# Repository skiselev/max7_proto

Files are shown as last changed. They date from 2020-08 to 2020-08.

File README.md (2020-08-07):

# MAX7 Proto
Prototyping Board for Altera MAX7000 CPLDs

## Table of Content
* [Introduction](#introduction)
* [Hardware Documentation](#hardware-documentation)
  * [Schematic and PCB Layout](#schematic-and-pcb-layout)
  * [Connectors and Jumpers](#connectors-and-jumpers)
  * [Bill of Materials](#bill-of-materials)
* [Programming](#programming)

## Introduction

MAX7 Proto is a prototyping board based on Altera MAX7000 series CPLDs. The board has pin headers on both sides, and it can be easily mounted on a breadboard. It also includes a 3.3V LDO, so that MAX7000AE CPLDs can be used. A DIP-8 oscillator socket is provided for the designs that requre a clock.

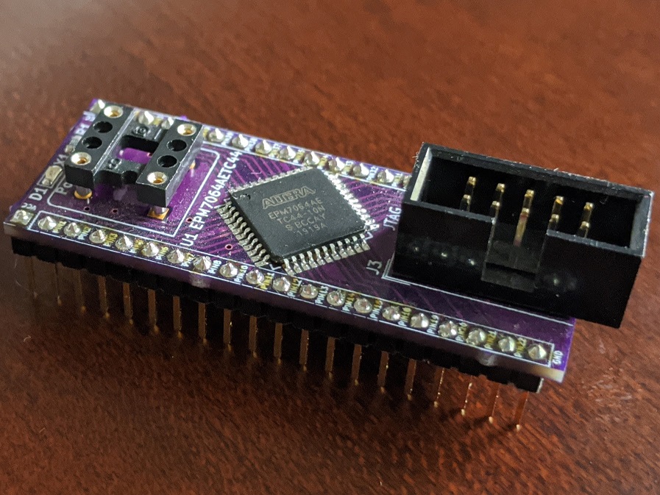
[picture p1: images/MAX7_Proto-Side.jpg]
MAX7 Proto Assembled Board Side View


## Hardware Documentation

### Schematic and PCB Layout

[Schematic](KiCad/MAX7_Proto-Schematic.pdf)

[PCB Layout](KiCad/MAX7_Proto-Board.pdf)

### Connectors and Jumpers

#### J1, J2 - CPLD Breakout Pin Headers
Pin   | Signal Name | Description               | Pin   | Signal Name | Description
----- | ----------- | ------------------------- | ----- | ----------- | -------------------------
J1-1  | VCC         | Power Supply - +5V        | J2-1  | VCC         | Power Supply - +5V
J1-2  | PIN1_TDI    | CPLD Pin 1; JTAG TDI; I/O | J2-2  | PIN44       | CPLD Pin 44; I/O
J1-3  | PIN2        | CPLD Pin 2; I/O           | J2-3  | PIN43       | CPLD Pin 43; I/O
J1-4  | PIN3        | CPLD Pin 3; I/O           | J2-4  | PIN42       | CPLD Pin 42; I/O
J1-5  | PIN5        | CPLD Pin 5; I/O           | J2-5  | PIN40       | CPLD Pin 40; In, OE2, GCLK2
J1-6  | PIN6        | CPLD Pin 6; I/O           | J2-6  | PIN39       | CPLD Pin 39; In, GCLRn
J1-7  | PIN7_TMS    | CPLD Pin 7; JTAG TMS; I/O | J2-7  | PIN38       | CPLD Pin 38; In, OE1n
J1-8  | PIN8        | CPLD Pin 8; I/O           | J2-8  | PIN37       | CPLD Pin 37; In, GCLK2
J1-9  | PIN10       | CPLD Pin 10; I/O          | J2-9  | PIN35       | CPLD Pin 35; I/O
J1-10 | PIN11       | CPLD Pin 11; I/O          | J2-10 | PIN34       | CPLD Pin 34; I/O
J1-11 | PIN12       | CPLD Pin 12; I/O          | J2-11 | PIN33       | CPLD Pin 33; I/O
J1-12 | PIN13       | CPLD Pin 13; I/O          | J2-12 | PIN32_TDO   | CPLD Pin 32; JTAG TDO; I/O
J1-13 | PIN14       | CPLD Pin 14; I/O          | J2-13 | PIN31       | CPLD Pin 31; I/O
J1-14 | PIN15       | CPLD Pin 15; I/O          | J2-14 | PIN30       | CPLD Pin 30; I/O
J1-15 | PIN18       | CPLD Pin 18; I/O          | J2-15 | PIN28       | CPLD Pin 28; I/O
J1-16 | PIN19       | CPLD Pin 19; I/O          | J2-16 | PIN27       | CPLD Pin 27; I/O
J1-17 | PIN20       | CPLD Pin 20; I/O          | J2-17 | PIN26_TCK   | CPLD Pin 26; JTAG TCK; I/O
J1-18 | PIN21       | CPLD Pin 21; I/O          | J2-18 | PIN25       | CPLD Pin 25; I/O
J1-19 | PIN22       | CPLD Pin 22; I/O          | J2-19 | PIN23       | CPLD Pin 23; I/O
J1-20 | GND         | Ground                    | J2-20 | GND         | Ground

#### J3 - JTAG - CPLD
Pin  | Signal Name | Description      | Pin  | Signal Name | Description
---- | ----------- | ---------------- | ---- | ---------- | ----------------
1    | TCK         | Test Clock       | 2    | GND         | Ground
3    | TDO         | Test Data Output | 4    | 3.3V        | Power Supply - +3.3V
5    | TMS         | Test Mode Select | 6    | PIN2        | No Connect
7    | NC          | No Connect       | 8    | NC          | No Connect
9    | TDI         | Test Data Input  | 10   | GND         | Ground

#### JP1 - LDO Bypass
Solder instead of U2 LDO when using a 5V CPLD

#### JP2 - Oscillator Connect
Solder to connect X1 oscillator to CPLD pin 37 / GCLK1

### Bill of Materials

[MAX7_Proto project on Mouser.com](https://www.mouser.com/ProjectManager/ProjectDetail.aspx?AccessID=f840bea3ac) - View and order all components except of the PCB.

[MAX7_Proto project on OSH Park](https://oshpark.com/shared_projects/AL0pME1G) - View and order the PCB.

Component type     | Reference | Description                                 | Quantity | Possible sources and notes 
------------------ | --------- | ------------------------------------------- | -------- | --------------------------
PCB                |           | MAX7 Proto PCB                              | 1        | Order from a PCB manufacturer of your choice using provided Gerber or KiCad files
Capacitor          | C1        | 10nF	0603 SMT                               | 1        | Mouser [77-V0603Y103KXJAC31X](https://www.mouser.com/ProductDetail/77-V0603Y103KXJAC31X)
Capacitor          | C2 - C7   | 100nF 0603 SMT                              | 6        | Mouser [77-VJ0603Y104JXJPBC](https://www.mouser.com/ProductDetail/77-VJ0603Y104JXJPBC)
Capacitor          | C8, C9    | 10uF	1210 SMT                               | 2        | Mouser [74-593D106X9016A2TE3](https://www.mouser.com/ProductDetail/74-593D106X9016A2TE3)
LED                | D1        | 0603 SMT Power/Green                        | 1        | Mouser [78-VLMG1300-GS08](https://www.mouser.com/ProductDetail/78-VLMG1300-GS08)
Connector          | J1, J2    | Pin Header 1x20, 2.54 mm pitch              | 2        | Mouser [649-68000-220HLF](https://www.mouser.com/ProductDetail/649-68000-220HLF)
Connector          | J5        | Pin Header 2x5, 2.54 mm pitch, Shrouded     | 1        | Mouser [710-61201021621](https://www.mouser.com/ProductDetail/710-61201021621)
Resistor           | R1        | 1 kOhm 0603 SMT                             | 1        | Mouser [71-CRCW0603-1.0K-E3](https://www.mouser.com/ProductDetail/71-CRCW0603-1.0K-E3)
Resistor           | R2 - R5   | 10 kOhm 0603 SMT                            | 4        | Mouser [71-CRCW0603-10K-E3](https://www.mouser.com/ProductDetail/71-CRCW0603-10K-E3) 
Integrated Circuit | U1        | EPM7064AETC44, Altera MAX 7000AE CPLD, TQFP-44 | 1     | Mouser [989-EPM7064AETC4410N](https://www.mouser.com/ProductDetail/989-EPM7064AETC4410N)
Integrated Circuit | U2        | TPS79333-EP                                 | 1        | Mouser [595-TPS79333DBVR](https://www.mouser.com/ProductDetail/595-TPS79333DBVR)
Socket             | X1        | Half can / DIP-8 Oscillator Socket          | 1        | Mouser [535-1108800](https://www.mouser.com/ProductDetail/535-1108800)
Crystal Oscillator | X1        | Half can / DIP-8 Oscillator, 5V             | 1        | Optional, frequency depends on the design requirements

## Programming

Use free Altera Quartus II 13.0sp1 Web Edition to program the CPLD. Newer Quartus versions do not support Altera MAX7000 CPLDs.

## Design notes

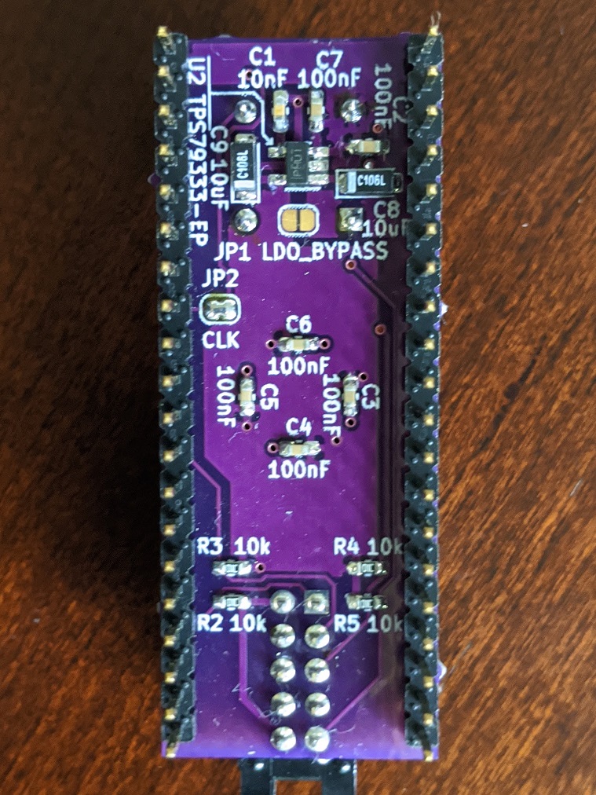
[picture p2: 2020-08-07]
images/MAX7_Proto-Bottom.jpg

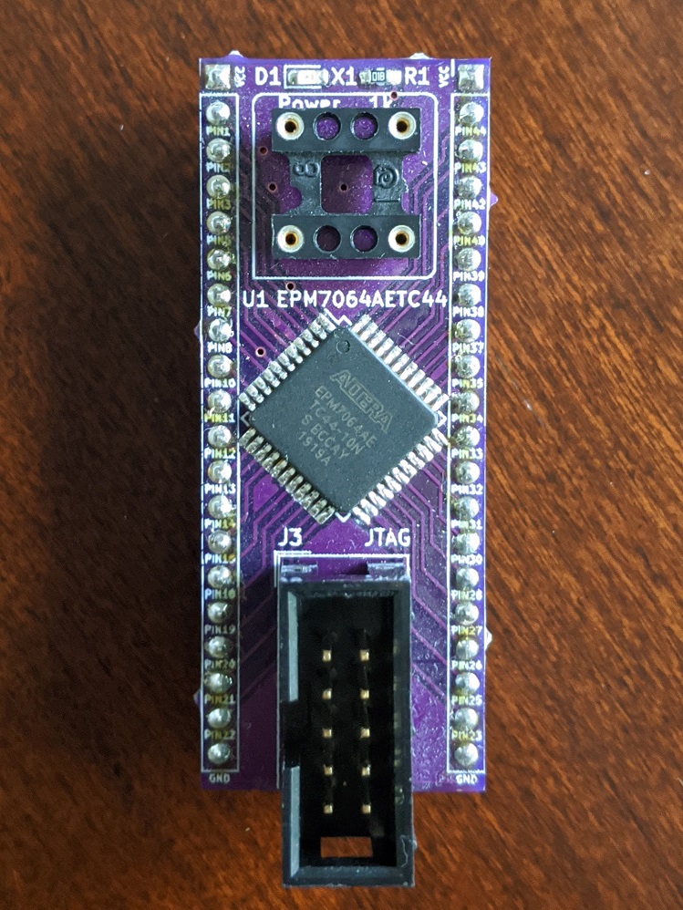
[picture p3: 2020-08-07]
images/MAX7_Proto-Top.jpg

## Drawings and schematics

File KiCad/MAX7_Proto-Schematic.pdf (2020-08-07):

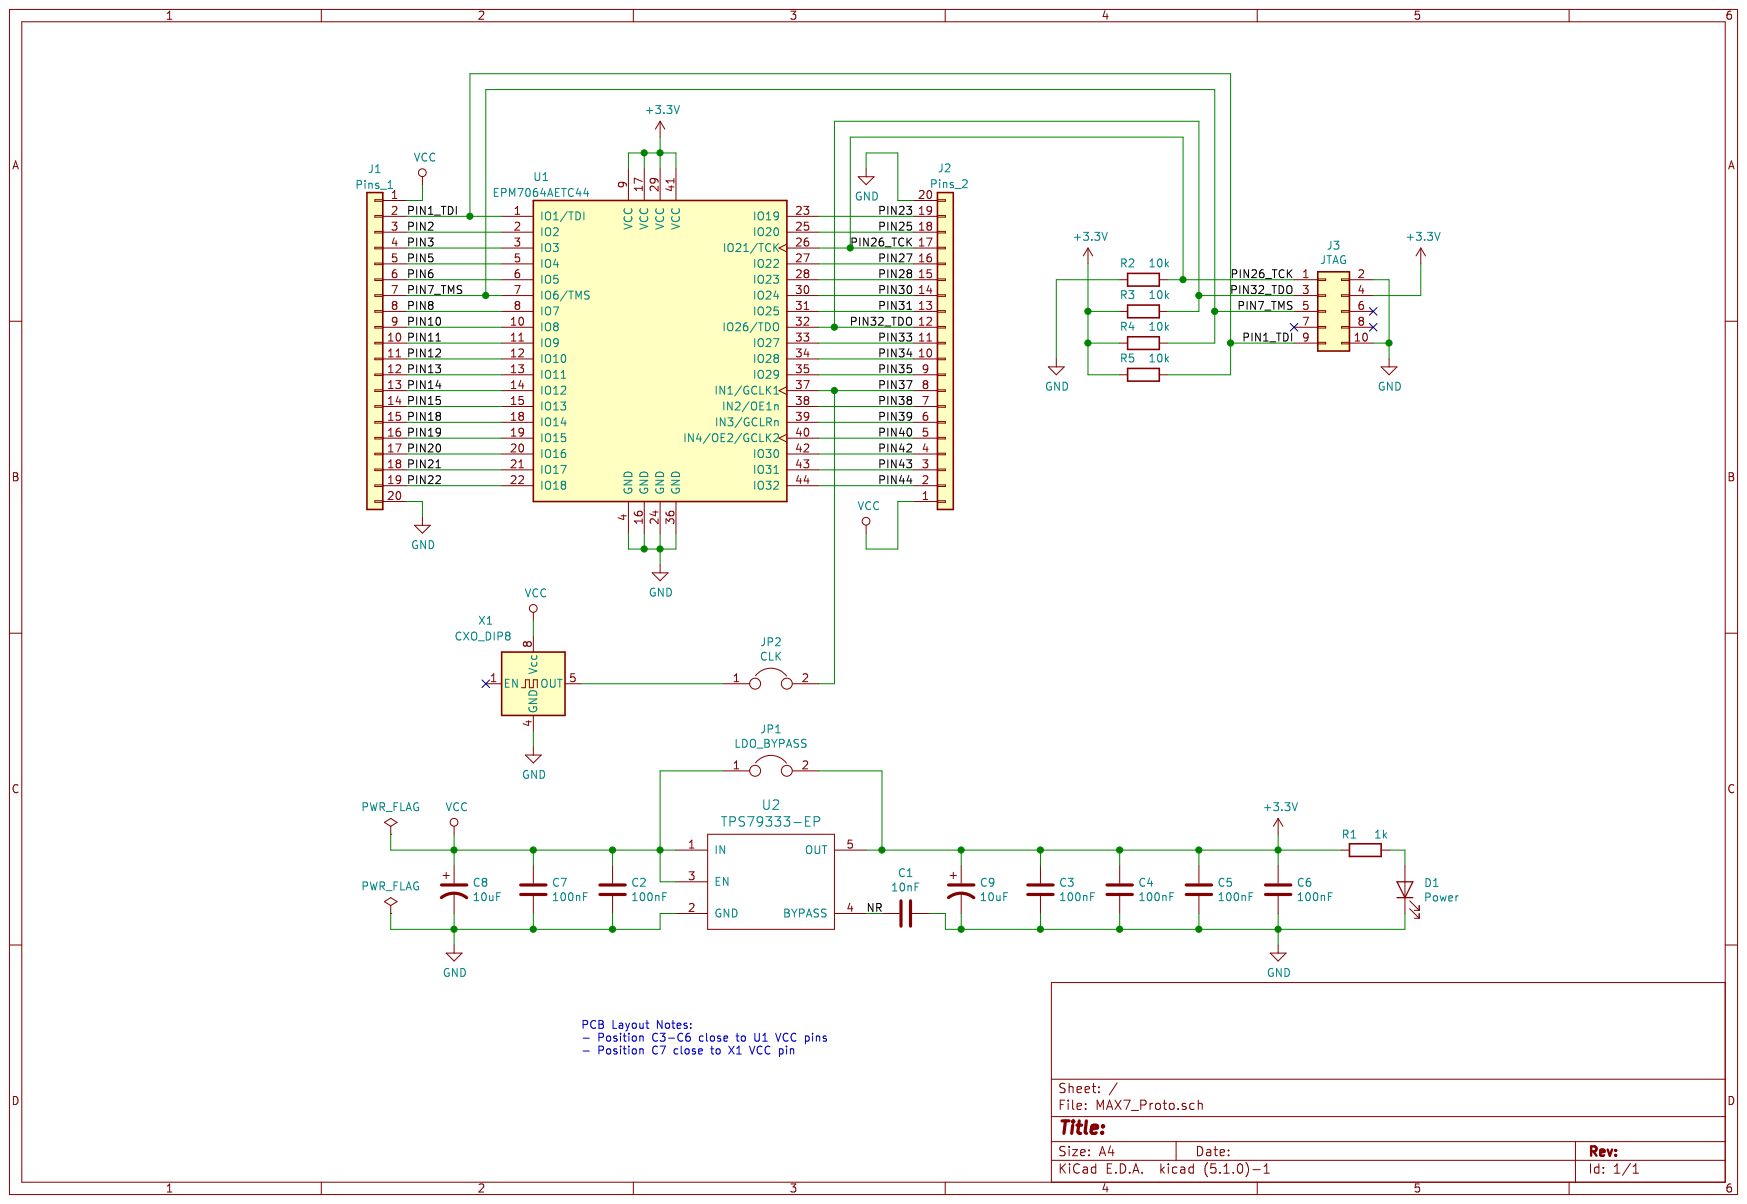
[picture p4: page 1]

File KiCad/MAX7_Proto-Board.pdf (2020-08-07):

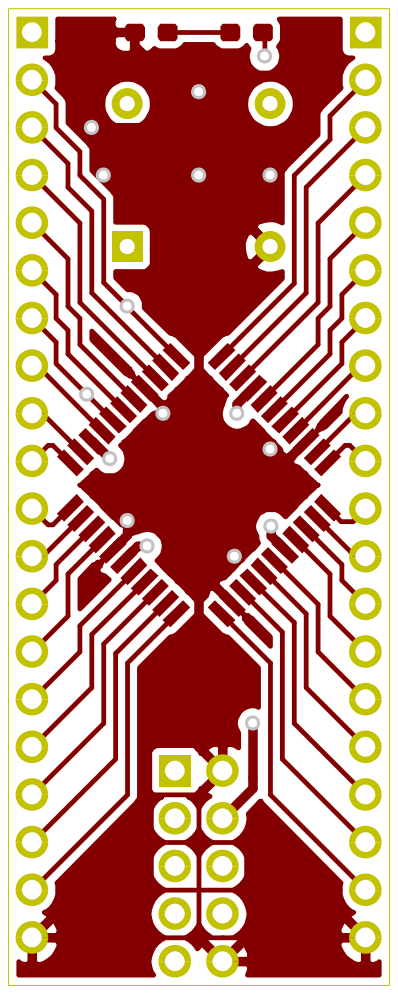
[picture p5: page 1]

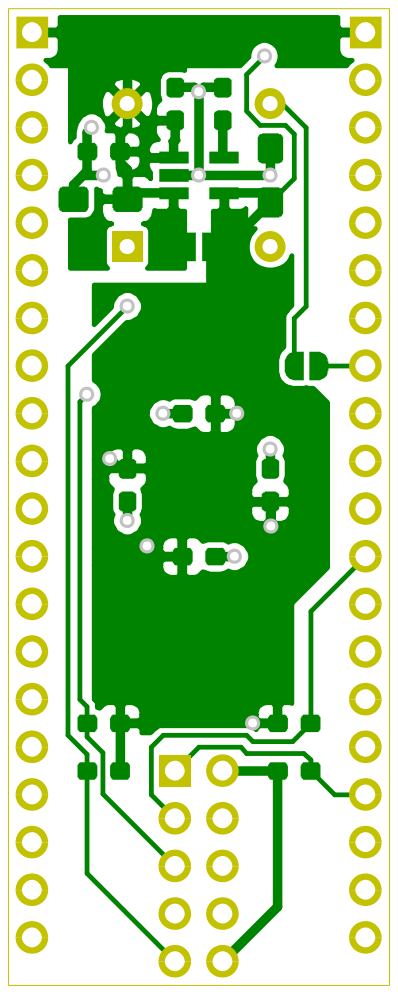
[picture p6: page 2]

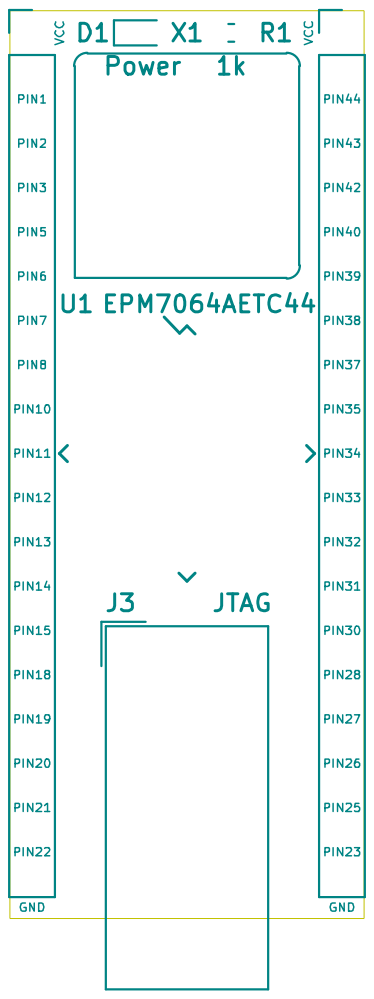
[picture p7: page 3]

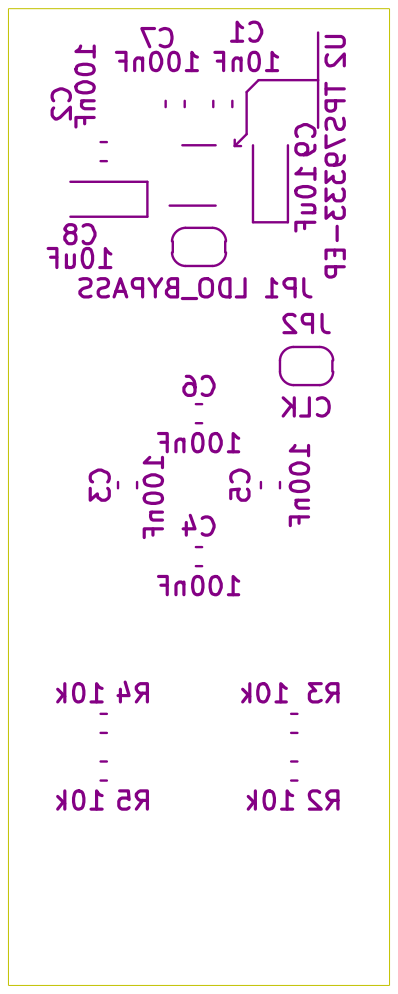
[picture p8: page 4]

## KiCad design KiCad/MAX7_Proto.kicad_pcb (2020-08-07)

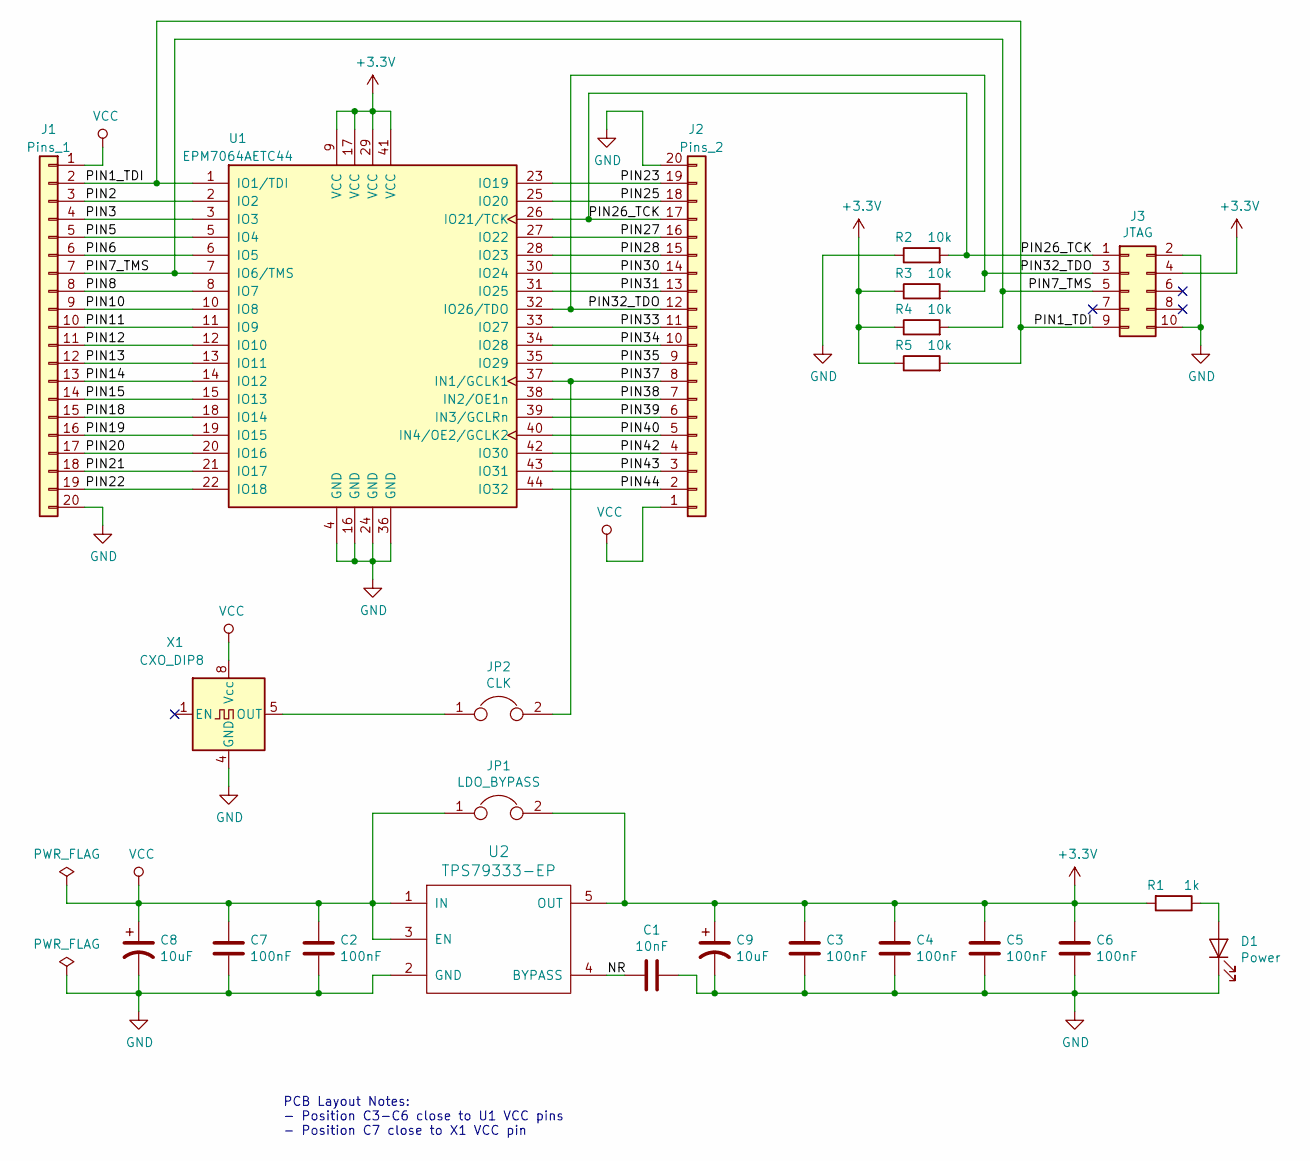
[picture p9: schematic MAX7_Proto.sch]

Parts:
C1: 10nF; C_0603_1608Metric_Pad1.05x0.95mm_HandSolder
C2, C3, C4, C5, C6, C7: 100nF; C_0603_1608Metric_Pad1.05x0.95mm_HandSolder
C8, C9: 10uF; CP_EIA-3216-10_Kemet-I_Pad1.58x1.35mm_HandSolder
D1: Power; LED_0603_1608Metric_Pad1.05x0.95mm_HandSolder
J1: Pins_1; PinHeader_1x20_P2.54mm_Vertical
J2: Pins_2; PinHeader_1x20_P2.54mm_Vertical
J3: JTAG; IDC-Header_2x05_P2.54mm_Vertical
JP1: LDO_BYPASS; SolderJumper-2_P1.3mm_Open_RoundedPad1.0x1.5mm
JP2: CLK; SolderJumper-2_P1.3mm_Open_RoundedPad1.0x1.5mm
R1: 1k; R_0603_1608Metric_Pad1.05x0.95mm_HandSolder
R2, R3, R4, R5: 10k; R_0603_1608Metric_Pad1.05x0.95mm_HandSolder
U1: EPM7064AETC44; TQFP-44_10x10mm_P0.8mm
U2: TPS79333-EP; SOT-23-5_HandSoldering
X1: CXO_DIP8; Oscillator_DIP-8

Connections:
+3V3: C3.1, C4.1, C5.1, C6.1, C9.1, J3.4, JP1.2, R1.2, R3.1, R4.1, R5.1, U1.9 (VCC), U1.17 (VCC), U1.29 (VCC), U1.41 (VCC), U2.5 (OUT)
/NR: C1.1, U2.4 (BYPASS)
/PIN1_TDI: J1.2, J3.9, R5.2, U1.1 (IO1/TDI)
/PIN2: J1.3, U1.2 (IO2)
/PIN3: J1.4, U1.3 (IO3)
/PIN5: J1.5, U1.5 (IO4)
/PIN6: J1.6, U1.6 (IO5)
/PIN7_TMS: J1.7, J3.5, R4.2, U1.7 (IO6/TMS)
/PIN8: J1.8, U1.8 (IO7)
/PIN10: J1.9, U1.10 (IO8)
/PIN11: J1.10, U1.11 (IO9)
/PIN12: J1.11, U1.12 (IO10)
/PIN13: J1.12, U1.13 (IO11)
/PIN14: J1.13, U1.14 (IO12)
/PIN15: J1.14, U1.15 (IO13)
/PIN18: J1.15, U1.18 (IO14)
/PIN19: J1.16, U1.19 (IO15)
/PIN20: J1.17, U1.20 (IO16)
/PIN21: J1.18, U1.21 (IO17)
/PIN22: J1.19, U1.22 (IO18)
/PIN23: J2.19, U1.23 (IO19)
/PIN25: J2.18, U1.25 (IO20)
/PIN26_TCK: J2.17, J3.1, R2.2, U1.26 (IO21/TCK)
/PIN27: J2.16, U1.27 (IO22)
/PIN28: J2.15, U1.28 (IO23)
/PIN30: J2.14, U1.30 (IO24)
/PIN31: J2.13, U1.31 (IO25)
/PIN32_TDO: J2.12, J3.3, R3.2, U1.32 (IO26/TDO)
/PIN33: J2.11, U1.33 (IO27)
/PIN34: J2.10, U1.34 (IO28)
/PIN35: J2.9, U1.35 (IO29)
/PIN37: J2.8, JP2.2, U1.37 (IN1/GCLK1)
/PIN38: J2.7, U1.38 (IN2/OE1n)
/PIN39: J2.6, U1.39 (IN3/GCLRn)
/PIN40: J2.5, U1.40 (IN4/OE2/GCLK2)
/PIN42: J2.4, U1.42 (IO30)
/PIN43: J2.3, U1.43 (IO31)
/PIN44: J2.2, U1.44 (IO32)
GND: C1.2, C2.2, C3.2, C4.2, C5.2, C6.2, C7.2, C8.2, C9.2, D1.1 (K), J1.20, J2.20, J3.2, J3.10, R2.1, U1.4 (GND), U1.16 (GND), U1.24 (GND), U1.36 (GND), U2.2 (GND), X1.4 (GND)
unnamed: D1.2 (A), R1.1
unnamed: JP2.1, X1.5 (OUT)
VCC: C2.1, C7.1, C8.1, J1.1, J2.1, JP1.1, U2.1 (IN), U2.3 (EN), X1.8 (Vcc)

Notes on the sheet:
PCB Layout Notes: - Position C3-C6 close to U1 VCC pins - Position C7 close to X1 VCC pin

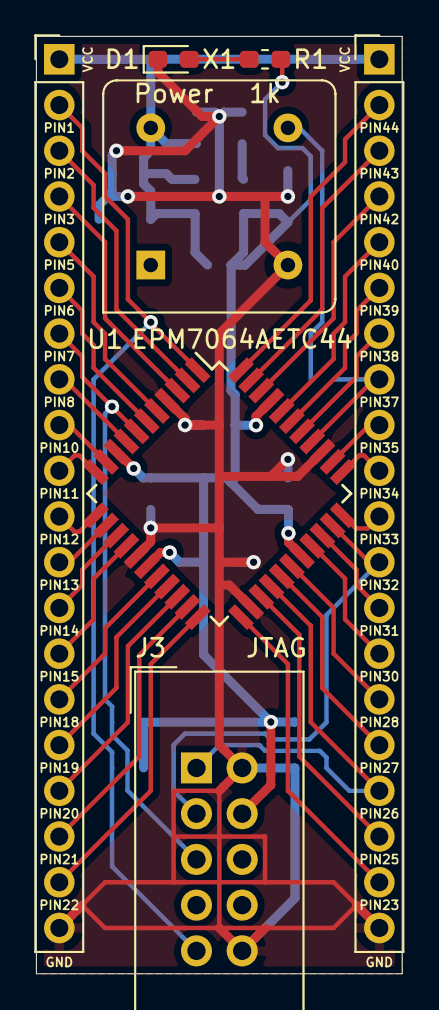
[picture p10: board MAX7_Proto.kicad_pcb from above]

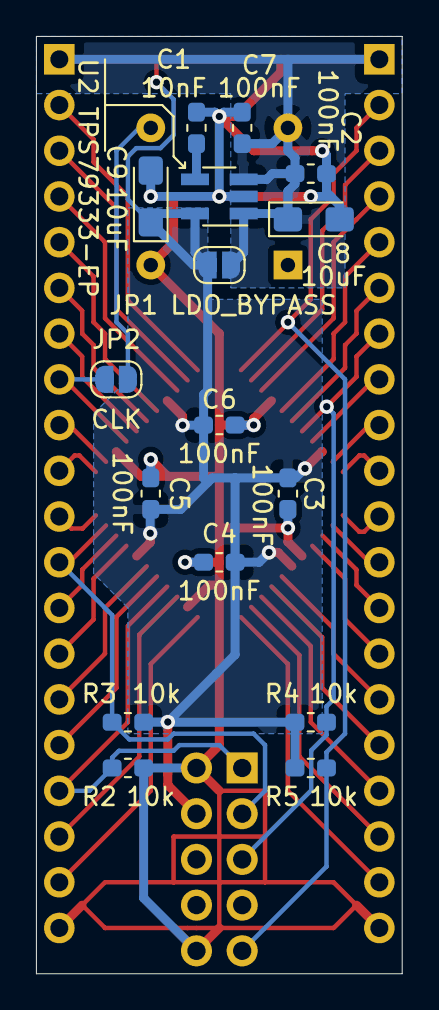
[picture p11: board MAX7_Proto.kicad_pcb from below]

Board: 2 copper layers, 20.3 x 52.1 mm, 23 parts (16 on the bottom side), 42 nets.
